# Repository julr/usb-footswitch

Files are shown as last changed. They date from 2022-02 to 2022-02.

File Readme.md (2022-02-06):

# USB Footswith
> Utilizing a STM32F4 microcontroller as configurable HID Keyboard with up to four buttons

## Hardware
This project is built around the "STM32 Black Pill" board which exists with multiple different controllers (STM32F411CE, STM32F401CC, STM32F401CE) which are all more or less binary compatible.
The linker file of the firmware is configured to only use up to 256 kiByte of flash memory so every version of the board should be supported, the actual usage is far below that.

Additionally up to 4 buttons and optional LEDs are needed. I used a Crate 3 Button AMP Footswitch where I replaced the toggle buttons with push buttons.

## Project Components
### Configurator
The Configurator folder contains the source of the desktop application written in C# and WPF to configure the device.

### Firmware
The Firmware folder contains the source of the microcontroller firmware. It is written in C++ utilizing the STM HAL LL drivers and tinyusb as USB stack.

#### Compiling the Firmware
The firmware was developed with VisuaGDB using the ARM toolchain (GCC 10.3.1) and the STM32 Device package (2022.01).
However it should be possible to compile the project without VisualGDB as long as the STM32F4 HAL is provided.

#### Install/Update
The easiest way to install or update the firmware is to use the internal DFU bootloader of the STM32F4. [STM32CubeProgrammer](https://www.st.com/en/development-tools/stm32cubeprog.html) or [dfu-util](http://dfu-util.sourceforge.net) can be used on the PC side to send the firmware to the device. 

### CAD
This folder contains 3D models for printing (a holder for the black pill board and a blind plug for 11 mm drill holes) and a sample schematic showing how to connect the buttons and LEDs to the board.

## Communication Protocol
The communication protocol for the HID configuration interface is described [here](https://github.com/julr/usb-footswitch/blob/main/ControlHidProtocol.md).

## Known Issues
Currently there is no support for multimedia keys. It should be possible to achieve this by adding an additional HID profile, see https://github.com/hathach/tinyusb/discussions/620.

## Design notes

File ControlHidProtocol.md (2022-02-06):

# General
The protocol of the control interface is request–response with the first byte being the message type and the other bytes are the payload.

# Requests
## Device Info Request (0x00)
Payload:
- Byte 1-7: Unused (don't care)

## Get Button Configuration Request (0x01)
Payload:
- Byte 1: Button (0 to number of buttons - 1)
- Byte 2-7: Unused (don't care)

## Set Button Configuration Request (0x02)
Payload:
- Byte 1: Button (0 to number of buttons - 1)
- Byte 2: Keyboard scan code
- Byte 3: Keyboard modifier
- Byte 4-7: Unused (don't care)

_Note: The configuration is only stored in RAM unless a save configuration request is issued. This allows for PC controlled profiles without stressing the flash of the microcontroller_

## Get Button Debounce Request (0x03)
Payload:
- Byte 1-7: Unused (don't care)

## Set Button Debounce Request (0x04)
Payload:
- Byte 1: Button debounce time in ms
- Byte 2-7: Unused (don't care)

## Get LED Configuration Request (0x05)
Payload:
- Byte 1-7: Unused (don't care)

### Possible Led modes
| Mode Byte | Description |
| --- | --- |
| 0x00 | Leds disabled |
| 0x01 | Leds always on |
| 0x02 | Led is on when button is pressed  |
| 0x03 | Led is off when button is pressed |

## Set LED Configuration Request (0x06)
Payload:
- Byte 1: Led mode
- Byte 2-7: Unused (don't care)

_Note: See Get LED Configuration Request (0x03) for possible LED modes_

## Save Configuration Request (0x07)
Payload:
- Byte 1-7: Unused (don't care)

## Start Bootloader Request (0x7F)
Payload:
- Byte 1-7: Unused (don't care)

_Note: The device will restart to the internal bootloader. No response will be sent._

# Responses
The return codes are defined as:
- 0x00: OK
- 0x01: Unknown command
- 0x02: Button out of range
- 0x03: Unknown led mode
- 0x04: Save failed

## Device Info Response (0x80)
Payload:
- Byte 1: Return code
- Byte 2: Firmware version mayor
- Byte 3: Firmware version minor
- Byte 4: Number of buttons
- Byte 5-7: Unused (don't care)

## Get Button Configuration Response (0x81)
Payload:
- Byte 1: Return code
- Byte 2: Button
- Byte 3: Keyboard scan code
- Byte 4: Keyboard modifier
- Byte 5-7: Unused (don't care)

_Note: Bytes 2 to 4 contain invalid/unknown data when the return code is not OK._

## Set Button Configuration Response (0x82)
Payload:
- Byte 1: Return code
- Byte 2: Button
- Byte 3-7: Unused (don't care)

## Get Button Debounce Response (0x83)
Payload:
- Byte 1: Return code
- Byte 2: Button debounce time in ms
- Byte 3-7: Unused (don't care)

## Set Button Debounce Response (0x84)
Payload:
- Byte 1: Return code
- Byte 2-7: Unused (don't care)

## Get LED Configuration Response (0x85)
Payload:
- Byte 1: Return code
- Byte 2: Current LED configuration
- Byte 3-7: Unused (don't care)

## Set LED Configuration Request (0x86)
Payload:
- Byte 1: Return code
- Byte 2-7: Unused (don't care)

## Save configuration Response (0x87)
Payload:
- Byte 1: Return code
- Byte 2-7: Unused (don't care)

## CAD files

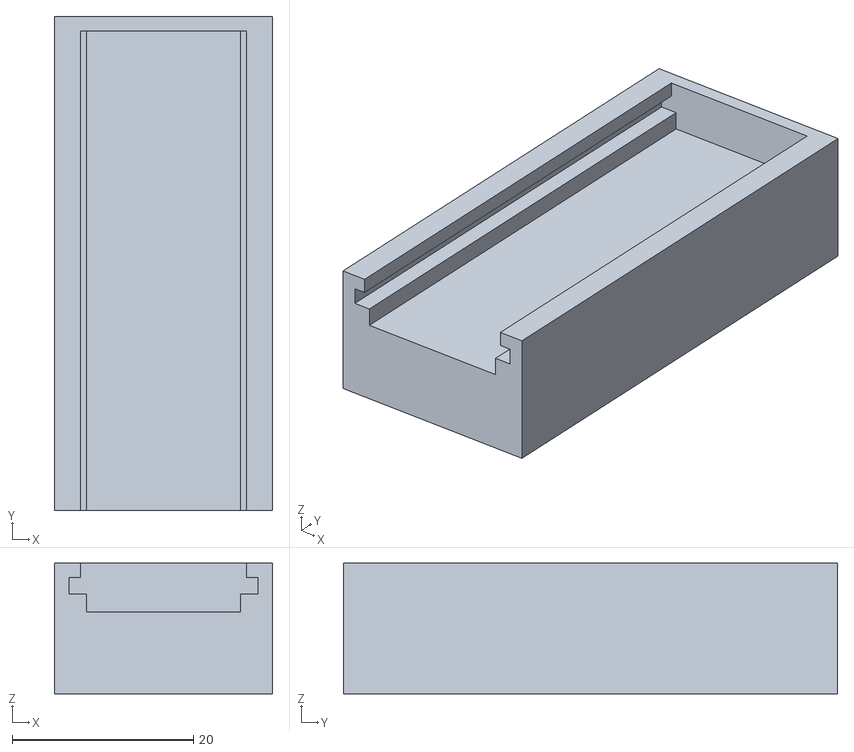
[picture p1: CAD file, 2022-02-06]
CAD/holder.stl
24.1 x 54.5 x 14.4

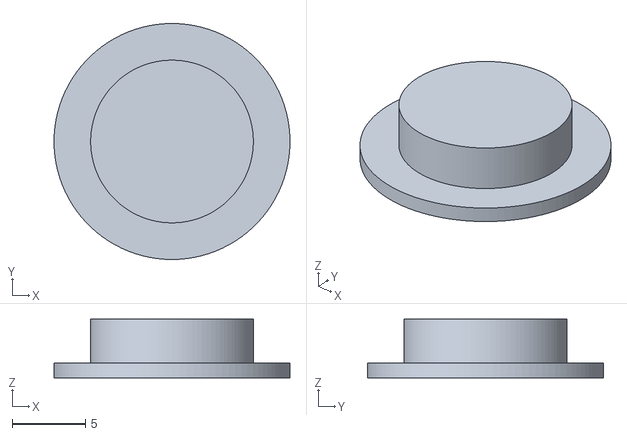
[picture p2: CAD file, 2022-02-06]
CAD/blind_cap.stl
16.1 x 16.1 x 4.00

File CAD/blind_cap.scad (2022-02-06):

$fn = 100;

hole_diameter = 11.1;
wall_thickness = 3;
rim = 2.5;
rim_thickness = 1;

cylinder(h=rim_thickness, d=hole_diameter+2*rim);
translate([0,0, rim_thickness])
    cylinder(h=wall_thickness, d=hole_diameter);    

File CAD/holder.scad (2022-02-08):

base_height = 9;
pinheader_gap = 2;
pinheader_distance = 18.3;
solder_distance = 17.0;
grip = 1.6;
pcb_cutaway = 0; // set this if the pcb was shortend
pcb_thickness = 1.8;
pcb_length = 52.81 +  0.09 - pcb_cutaway; //Taken from original drawing
pcb_width = 20.78 + 0.12; //Taken from original drawing

debug_cutout_width = 11.5;
debug_cutout = false;

rail = true;
rail_height = 4;
rail_depth = 4;

difference()
{
    //Outer holder dimensions
    cube([pcb_width + grip * 2, pcb_length + grip, base_height + pinheader_gap + pcb_thickness+ grip]);
    union()
    {
        // PCB
        translate([grip, 0, base_height + pinheader_gap])
            cube([pcb_width, pcb_length, pcb_thickness]);

        // Space for pinheader on top
        translate([(pcb_width + grip * 2 - pinheader_distance)/2, 0, base_height + pinheader_gap + pcb_thickness])
          cube([pinheader_distance, pcb_length, grip]);

        // Space for solder of pin header on bottom
        translate([(pcb_width + grip * 2 - solder_distance)/2, 0, base_height])
           cube([solder_distance, pcb_length, pinheader_gap]);

        if(debug_cutout == true) // Cutout for SWD connector
        {
            translate([(pcb_width + grip * 2 - debug_cutout_width)/2, pcb_length, base_height + pinheader_gap + pcb_thickness])
                cube([debug_cutout_width, grip, grip]);
        }

        if(rail == true) // Cutout for rail in case
        {
            cube([pcb_width + grip * 2, rail_depth, rail_height]);
        }
    }
}

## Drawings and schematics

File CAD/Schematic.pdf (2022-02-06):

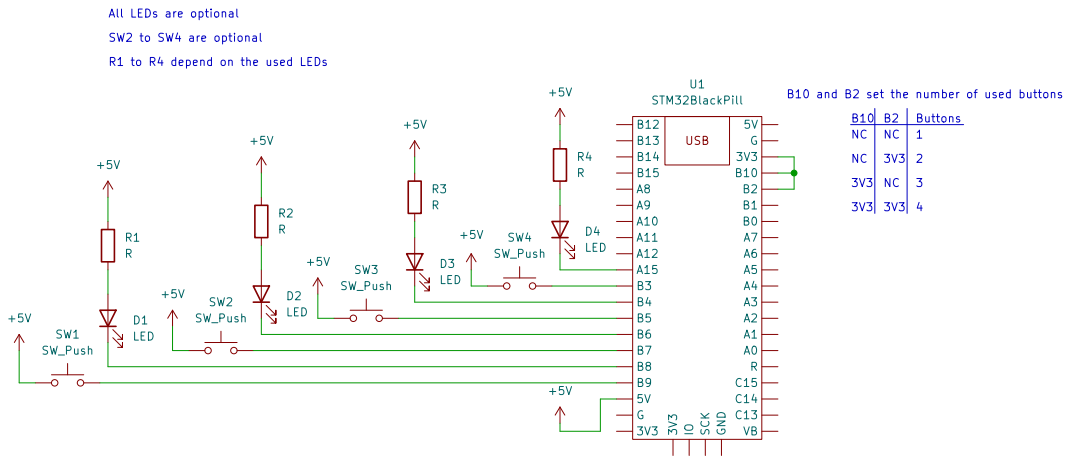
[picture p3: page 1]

Buttons B10 and B2 set the number of used buttons 3V3

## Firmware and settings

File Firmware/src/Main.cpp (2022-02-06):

#include "Board.h"
#include "ConfigManager.h"
#include "USB.h"

int main(void)
{   
    Board::initialize();
    ConfigManager::initialize();
#ifdef DEBUG
    USB::initialize();
#else
    USB::initialize(false); // Disable onboard LED for release builds
#endif
    Board::resetButtonStates();
    
    while (true)
    {
        USB::task();
    }

    return 0;
}

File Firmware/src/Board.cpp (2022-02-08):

#include "Board.h"

#include "stm32f4xx_ll_gpio.h"
#include "stm32f4xx_ll_bus.h"
#include "stm32f4xx_ll_rcc.h"
#include "stm32f4xx_ll_pwr.h"
#include "stm32f4xx_ll_system.h"

#include "tusb.h"

#include "ConfigManager.h"

// Class member
volatile std::uint32_t Board::tickCount_ {0U};
char Board::serialNumber_[14]{ '0' };
Board::ButtonState Board::buttonStates_[MAX_BUTTON_COUNT];

std::uint32_t Board::buttonCount_{0};

// USB ISR
extern "C" void OTG_FS_IRQHandler(void)
{
    tud_int_handler(0);
}

// SysTick ISR
extern "C" void SysTick_Handler(void)
{
    Board::tickCount_++;
    Board::debounceButtons();
}

//--------------------------------------------------------------------+
// MACRO TYPEDEF CONSTANT ENUM
//--------------------------------------------------------------------+

// Onboard LED
static GPIO_TypeDef* ONBOARDLED_PORT{GPIOC};
static constexpr std::uint32_t ONBOARD_LED_PIN{LL_GPIO_PIN_13};

// Onboard Button
static GPIO_TypeDef* ONBOARD_BUTTON_PORT{GPIOA};
static constexpr std::uint32_t ONBOARD_BUTTON_PIN{LL_GPIO_PIN_0};

// Foot buttons
static GPIO_TypeDef* FOOT_BUTTONS_PORT{GPIOB};
static constexpr std::uint32_t FOOT_BUTTON_1_PIN{LL_GPIO_PIN_9};
static constexpr std::uint32_t FOOT_BUTTON_2_PIN{LL_GPIO_PIN_7};
static constexpr std::uint32_t FOOT_BUTTON_3_PIN{LL_GPIO_PIN_5};
static constexpr std::uint32_t FOOT_BUTTON_4_PIN{LL_GPIO_PIN_3};

// Foot button leds
static GPIO_TypeDef* FOOT_LED_1_PORT{GPIOB};
static constexpr std::uint32_t FOOT_LED_1_PIN{LL_GPIO_PIN_8};
static GPIO_TypeDef* FOOT_LED_2_PORT{GPIOB};
static constexpr std::uint32_t FOOT_LED_2_PIN{LL_GPIO_PIN_6};
static GPIO_TypeDef* FOOT_LED_3_PORT{GPIOB};
static constexpr std::uint32_t FOOT_LED_3_PIN{LL_GPIO_PIN_4};
static GPIO_TypeDef* FOOT_LED_4_PORT{GPIOA};
static constexpr std::uint32_t FOOT_LED_4_PIN{LL_GPIO_PIN_15};

// Board config
static GPIO_TypeDef* BOARD_CONFIG_PORT{GPIOB};
static constexpr std::uint32_t BOARD_CONFIG_1_PIN{LL_GPIO_PIN_2};
static constexpr std::uint32_t BOARD_CONFIG_2_PIN{LL_GPIO_PIN_10};

void Board::initialize()
{
    initializeClock();
    SystemCoreClockUpdate();
    initializePins();
    readChipIdentifiaction();
    readBoardConfig();
    
    // the board doesn't use VBUS sense (B device) so disable it
    USB_OTG_FS->GCCFG |= USB_OTG_GCCFG_NOVBUSSENS;
    USB_OTG_FS->GCCFG &= ~(USB_OTG_GCCFG_VBUSBSEN | USB_OTG_GCCFG_VBUSASEN);
    
    // setup SysTick as 1ms tick timer
    SysTick_Config(SystemCoreClock / 1000);
}

void Board::setLed(LED led, bool on) //LED is low active
{
    GPIO_TypeDef* port;
    std::uint32_t pin;
    
    switch (led)
    {
    case LED::ONBOARD:
        if (on)
        {
            LL_GPIO_ResetOutputPin(ONBOARDLED_PORT, ONBOARD_LED_PIN);
        }
        else
        {
            LL_GPIO_SetOutputPin(ONBOARDLED_PORT, ONBOARD_LED_PIN);
        }
        return;
        
    case LED::FOOT_1:
        port = FOOT_LED_1_PORT;
        pin = FOOT_LED_1_PIN;
        break;
        
    case LED::FOOT_2:
        port = FOOT_LED_2_PORT;
        pin = FOOT_LED_2_PIN;
        break;
        
    case LED::FOOT_3:
        port = FOOT_LED_3_PORT;
        pin = FOOT_LED_3_PIN;
        break;
        
    case LED::FOOT_4:
        port = FOOT_LED_4_PORT;
        pin = FOOT_LED_4_PIN;
        break;
        
    default:
        return;
    }
    
    LL_GPIO_SetPinMode(port, pin, on ? LL_GPIO_MODE_OUTPUT : LL_GPIO_MODE_INPUT);
}

void Board::initializeClock()
{   
    // Power Control Clock
    LL_AHB1_GRP1_EnableClock(LL_APB1_GRP1_PERIPH_PWR);
    
    // Set flash latency
    LL_FLASH_SetLatency(LL_FLASH_LATENCY_2);
    
    // The voltage scaling allows optimizing the power consumption when the device is
    // clocked below the maximum system frequency, to update the voltage scaling value
    // regarding system frequency refer to product datasheet.
    LL_PWR_SetRegulVoltageScaling(LL_PWR_REGU_VOLTAGE_SCALE2);
    
    // Enable HSE Oscillator and activate PLL with HSE as source
    // Main Clock will be set to 84 Mhz
    LL_RCC_HSE_Enable();
    while (LL_RCC_HSE_IsReady() != 1) ;
    
    constexpr std::uint32_t PLLM {HSE_VALUE / 1000000};
    constexpr std::uint32_t PLLN {336};
    LL_RCC_PLL_ConfigDomain_SYS(LL_RCC_PLLSOURCE_HSE, PLLM, PLLN, LL_RCC_PLLP_DIV_4);
    LL_RCC_PLL_ConfigDomain_48M(LL_RCC_PLLSOURCE_HSE, PLLM, PLLN, LL_RCC_PLLQ_DIV_7);
    LL_RCC_PLL_Enable();
    while (LL_RCC_PLL_IsReady() != 1) ;
    
    // Select PLL as system clock source and configure the HCLK, PCLK1 and PCLK2
    // clocks dividers
    LL_RCC_SetAHBPrescaler(LL_RCC_SYSCLK_DIV_1);
    LL_RCC_SetAPB1Prescaler(LL_RCC_APB1_DIV_2);
    LL_RCC_SetAPB2Prescaler(LL_RCC_APB2_DIV_1);
    LL_RCC_SetSysClkSource(LL_RCC_SYS_CLKSOURCE_PLL);
    while (LL_RCC_GetSysClkSource() != LL_RCC_SYS_CLKSOURCE_STATUS_PLL) ;
    
    // GPIO Clocks
    LL_AHB1_GRP1_EnableClock(LL_AHB1_GRP1_PERIPH_GPIOA);
    LL_AHB1_GRP1_EnableClock(LL_AHB1_GRP1_PERIPH_GPIOB);
    LL_AHB1_GRP1_EnableClock(LL_AHB1_GRP1_PERIPH_GPIOC);
    
    // USB Clock
    LL_AHB2_GRP1_EnableClock(LL_AHB2_GRP1_PERIPH_OTGFS);
}
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

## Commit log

2022-02-08 default buttons set to 1, 2, 3, 4
2022-02-08 bug in scad model fixed
    [holder.scad]
